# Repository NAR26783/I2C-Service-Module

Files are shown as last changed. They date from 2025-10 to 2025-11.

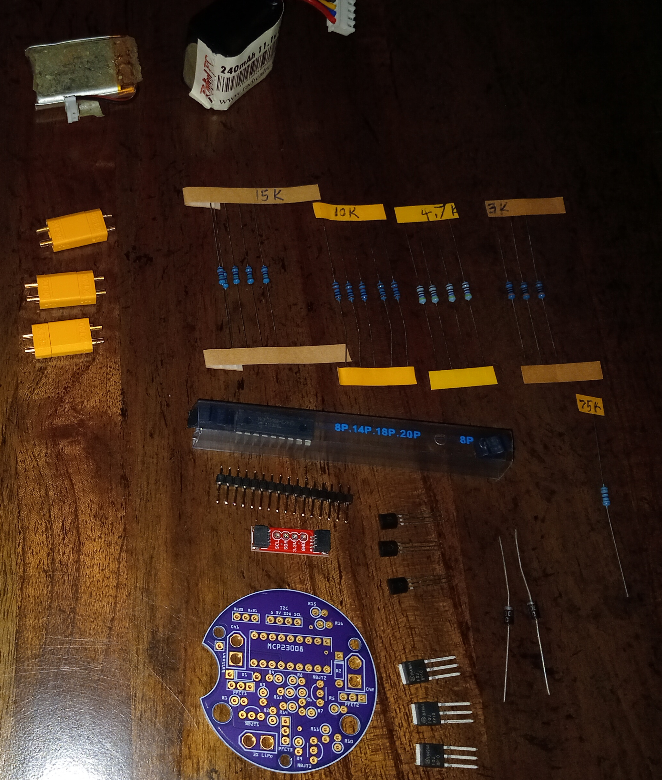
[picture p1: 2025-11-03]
I2CServiceModulePCB&Parts.jpg

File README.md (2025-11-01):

Simple, 2 channel, IIC module to start a deployment charge, ignite a second stage or light a high-current LED string!  Program it the way YOU want, it's your rocket.  Use two for up to  four channels, just jumper the address high for 0x23 and low for 0x21.  You can leave PWRON off for startup and during preflight operations for safety, and the PNP FET architechture means no inadvertant firings from grounding.  BATTMON can be used as a double check to ensure a firing battery IS connected.  The continuity circuits will show ONLY that there's a way to ground, no indication of high resistance or dead  short.  TST1 puts 3v3 into your igniter through a 15k resistor AND a diode.  So, if Sn1 reads HIGH, there's no path to ground and continuity fails. Ch1 HIGH connects the 3S LiPo plus side to the channel 1 circuit.  TST2, Sn2 and Ch2 operate in a similar fashon. 

OSHPark linl for PCB:
https://oshpark.com/shared_projects/tfre3jx1

The recommend battery for this unit is the Radical R/C, RRC 3S 240mAh Lipo Super High Discharge 20C
https://www.radicalrc.com/item/RRC-3S-240mAh-Lipo-Super-High-Discharge-20C-108260

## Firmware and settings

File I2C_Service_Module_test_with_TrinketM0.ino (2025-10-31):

//*******************************************************
//*   I2C_Deployment_Module_test_with_TrinketM0.ino     *
//*   Test Script code for the I2C Deployment Module    *
//*       attached to an Adafruit Trinket M0            *
//* Provides framework for adding sensors & ITDT Logic  *
//*              Mike Loman 8/12/25                     *
//*******************************************************
//  https://oshpark.com/shared_projects/tfre3jx1
//  test code assumes:
//   1.  Single THT I2C Deployment Module on bus
//   2.  Test config:  Xmas lights connected to Ch1 & Ch2, 3S LiPo connected 
//   3.  Ch1 is Drogue and Ch2 is Main
//   4.  Adafruit Trinket M0 is MCU driving the I2C Deployment Module and 
//   5.  On-board Dotstar is primary HMI

//   ****************   set Global environment   *****************
  //  include libraries
#include <Adafruit_DotStar.h>
  #include <Adafruit_MCP23XXX.h>
  #include <Adafruit_MCP23X08.h>

//     ##############      I2C Service Module Silk                  #################  
  #define TEST1      2
  #define TEST2      4
  #define DROGUE     1   //  CH1,  blue pigtail
  #define MAIN       6   //  CH2,  yellow pigtrail  
  #define SNDROGUE   0
  #define SNMAIN     7
  #define PWRON      5
  #define BATTMON    3
  
//     ##############     M0 Trinket Pinouts      #################  
#define AudioPin   A0
#define FireBatt   A2
#define VBATT      A3
#define DotData     7  // Digital #7 - You can't see this pin but it is connected to the internal RGB DotStar data in pin
#define DotClock    8  // Digital #8 - You can't see this pin but it is connected to the internal RGB DotStar clock in pin
#define OnBoardLED 13  // Digital #13 - You can't see this pin but it is connected to the little red status LED

    
  //   instantiate libraries
  Adafruit_DotStar led(1, DotData, DotClock, DOTSTAR_BRG);
  Adafruit_MCP23X08 DD;
    
  //  declare variable types
  bool ArmReq, TestReq, DrogueReq, MainReq, ARMED, FAIL1, FAIL2, DrogueTimerSet, MainTimerSet, TestTimerSet;
  long TestTimer, DrogueTimer, MainTimer;
  enum conditions {
    awaiting_1stTest, 
    awaiting_Arm, 
    awaiting_2ndTest, 
    awaiting_Apogee, 
    awaiting_MainAlt, 
    awaiting_Landing
  }FLTCON;
  
//  *****************************  END Globals - Begin Setup   ****************  
void setup() {
  
  //  *************  start Serial - uncomment while (!Serial); to ensure connection  ****************  
  Serial.begin(115200);
//  while (!Serial);
  Serial.println("I2C Deployment Module Test!");
  
  //  *********  start Qt Py Built-in NeoPixel under Adafruit NeoPixel driver  ****************  
  led.begin();
  led.clear();  // Set all pixel colors to 'off'
  led.show();   // Send the updated pixel colors to the hardware.    
  
  //  *********  start I2C Deployment Module under Adafruit MCP23008 drivers  ****************  
  if (!DD.begin_I2C(0x23)) {   //  Module I2C address is 0x21 or 0x23. Default is 0x21.
    Serial.println("Error.  No MCP23008 detected on 0x21...");
  }
  // configure Test, Arm and Ch pins for output
  DD.pinMode(TEST1, OUTPUT);
  DD.pinMode(TEST2, OUTPUT);
  DD.pinMode(PWRON, OUTPUT);
  DD.pinMode(DROGUE, OUTPUT);
  DD.pinMode(MAIN, OUTPUT);
  
  // configure Sn and FireBatt pins for input
  DD.pinMode(BATTMON, INPUT); 
  DD.pinMode(SNDROGUE, INPUT); 
  DD.pinMode(SNMAIN, INPUT); 
  
  delay(100);  //   give it a few...
  //  set all outputs LOW
  DD.digitalWrite(TEST1, LOW);
  DD.digitalWrite(TEST2, LOW);
  DD.digitalWrite(PWRON, LOW);
  DD.digitalWrite(DROGUE, LOW);
  DD.digitalWrite(MAIN, LOW);

//  set/initialize flight options
  FLTCON = awaiting_1stTest;
  
//  *******************  END Setup - Begin loop  ********************************   
}
void loop() {
//  *****************  read sensors  *******************************    

//  ************  calculate derived values  ************************

//  *****************   set bools   ********************************
  //  For the test script, just use timer triggers vs. sensor inputs
  //  Kinda makes it into a PET2....
  switch (FLTCON){
    case awaiting_1stTest:
      if(millis()>5000){
        TestReq = true;       //  should light Dotstar blue
        Serial.println("Continuity test requested");        
        FLTCON = awaiting_Arm;
      }
    break;
    case awaiting_Arm:
      if(millis()>10000){
        ArmReq = true;
        Serial.println("Arming requested");               
        FLTCON = awaiting_2ndTest;
      }
    break;
    case awaiting_2ndTest:
      if(millis()>15000){
        TestReq = true;       //  should light Dotstar green
        Serial.println("2nd continuity test requested");               
        FLTCON = awaiting_Apogee;
      }
    break;
    case awaiting_Apogee:
      if(millis()>20000){
        DrogueReq = true;       //  should light Ch1 Xmas light
        Serial.println("Drogue power requested");               
        FLTCON = awaiting_MainAlt;
      }
    break;
    case awaiting_MainAlt:
      if(millis()>25000){
        MainReq = true;       //  should light Ch2 Xmas light
        Serial.println("Main power requested");               
        FLTCON = awaiting_Landing;
      }
    break;
    case awaiting_Landing:


    break;
  }

//  *****************   Take Actions   ********************************
  if(ArmReq){
    DD.digitalWrite(PWRON, HIGH);
    ArmReq = false;
    ARMED = DD.digitalRead(BATTMON);
              Serial.print("ARMED   ");
          Serial.println(ARMED);
  }
  if(TestReq){
    DD.digitalWrite(TEST1, HIGH);
    DD.digitalWrite(TEST2, HIGH);
    TestTimer = millis()+500l;
    TestTimerSet=true;
    TestReq=false;
  }
  if(DrogueReq){
    DD.digitalWrite(DROGUE, HIGH);
    DrogueTimer = millis()+2000l;  
    DrogueTimerSet=true;
    DrogueReq=false;
  }
  if(MainReq){
    DD.digitalWrite(MAIN, HIGH);
    MainTimer = millis()+2000l; 
    MainTimerSet=true;
    MainReq=false;
  }

//  *****************   check timers   ********************************
  if(TestTimerSet && TestTimer<=millis()){
    //  Read and Report continuity test results
    led.clear();
    led.setPixelColor(0, led.Color(150, 150, 150));    //  Display white for default/unknown    
    FAIL1=DD.digitalRead(SNDROGUE);
          Serial.print("FAIL1   ");
          Serial.println(FAIL1);
    FAIL2=DD.digitalRead(SNMAIN);
          Serial.print("FAIL2   ");
          Serial.println(FAIL2);    
    if(!FAIL1 && !FAIL2 && ARMED){
      Serial.println("Ready to Launch!");
      led.clear();
      led.setPixelColor(0, led.Color(150, 0, 0));    //  Display green
    }
    if(FAIL1){
      Serial.println("Drogue failed continuity check...");
      led.clear();
      led.setPixelColor(0, led.Color(0, 150, 0));    //  Display red
    }
    if(FAIL2){
      Serial.println("Main failed continuity check...");
      led.clear();
      led.setPixelColor(0, led.Color(150, 150, 0));  //  Display yellow
    }
    if(FAIL1 && FAIL2){
      Serial.println("BOTH failed continuity check...");
      led.clear();
      led.setPixelColor(0, led.Color(0, 50, 150));  //  Display purple
    }
    if(!ARMED){
      Serial.println("Not Armed - Battery may be weak or disconnected...");
      led.clear();
      led.setPixelColor(0, led.Color(0, 0, 150));    //  Display blue
    }
    led.show();
    DD.digitalWrite(TEST1, LOW);
    DD.digitalWrite(TEST2, LOW);
    TestTimerSet=false;    
  }  
  if(DrogueTimerSet && DrogueTimer<=millis()){
    DD.digitalWrite(DROGUE, LOW);
    Serial.println("Drogue power off");  
    DrogueTimerSet=false;
  }
  if(MainTimerSet && MainTimer<=millis()){
    DD.digitalWrite(MAIN, LOW);
    Serial.println("Main power off");  
    MainTimerSet=false;
  }
  
//  *****************   END loop   ********************************
}

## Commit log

2025-10-31 Add module description and battery recommendation to README
    Added a description of the IIC module functionality and battery recommendation.
2025-11-01 Update README with PCB link and formatting changes
    Added OSHPark link for PCB and improved formatting.
